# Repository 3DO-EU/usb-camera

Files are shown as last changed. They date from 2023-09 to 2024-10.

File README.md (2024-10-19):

# 3DO 4K USB CAMERA

**This repository is archived. Please visit the new project at [https://github.com/3DO-EU/Enclosure-Nozzle-Camera-V2](https://github.com/3DO-EU/Enclosure-Nozzle-Camera-V2)**

3DO Discord Server

The 3DO USB Camera is a compact USB camera based on the IMX485 sensor, designed for use with 3D printers.
This repository contains reference designs; additional resources may be found on printables.com or similar platforms.

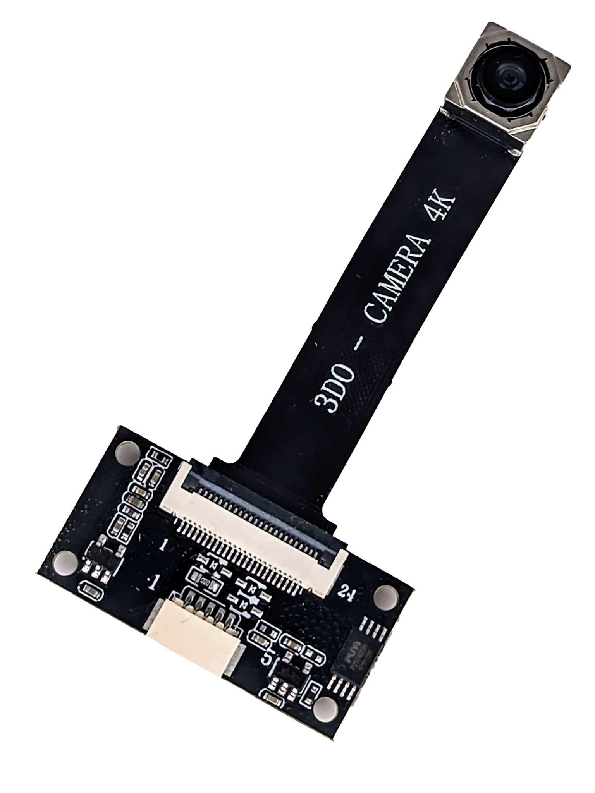
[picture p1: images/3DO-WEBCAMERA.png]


| | 4K (Sony IMX258) |
|---|---|
| Sensor Size | 1/3.06 |
| Mega-Pixel | 13MP |
| Frame Rate* | 30 FPS at 4K, 60 FPS at 1080P* |
| Lens type | Auto Focus |
| Focus length | 5 - ∞ cm |
| FoV | 120 Deg |
| FPC length | 5cm |
| Operating temperature** | -20°C TO 65°C |
| Storage temperature | -40°C TO 80°C |

_*These frame rates represent what the camera can achieve when directly connected, such as in OBS Studio or the Windows webcam app._

_When streaming through Crowsnest on a Raspberry Pi or a similar device, two factors limit your performance: GPU power and bandwidth._

_The new version of Crowsnest supports WebRTC/H.264 streaming, significantly reducing bandwidth requirements, making it less of a concern. However, when using the WebRTC streaming function, your GPU's encoding capabilities become the limiting factor (For Raspberry Pi 4, the GPU is limited to 1080p at 38 FPS and cannot encode 4K)._

_If you opt for the MJPEG stream in Crowsnest, no encoding is necessary, eliminating GPU limitations. However, this method requires considerably more bandwidth, so your FPS will be restricted by the available network bandwidth (using an Ethernet cable instead of Wi-Fi is recommended)._

## Folders
- printers (mounts for different printers)
- hardware (similar to [3DO Nozzle camera](https://github.com/3DO-EU/nozzle-camera/tree/main/hardware))

## Pinout
The PCB uses a 5P 1.0mm pitch connector.
| Pin No. | Function | Color |
|---|---|---|
| 1 | USB 5VDC | Red |
| 2 | Data - | White |
| 3 | Data + | Green |
| 4 | USB -VDC/GND | Black |
| 5 | GND/Shield | Black (heat shrink)  |

Wire number 5 is an optional shield/drain wire, though it will work without it; we recommend installing it.

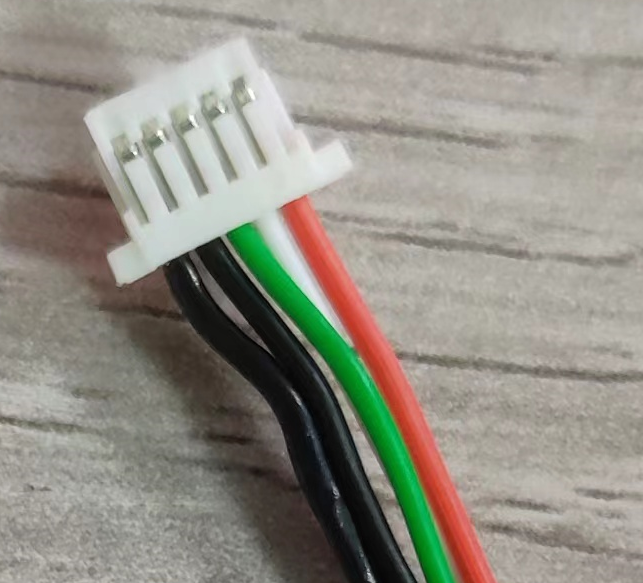
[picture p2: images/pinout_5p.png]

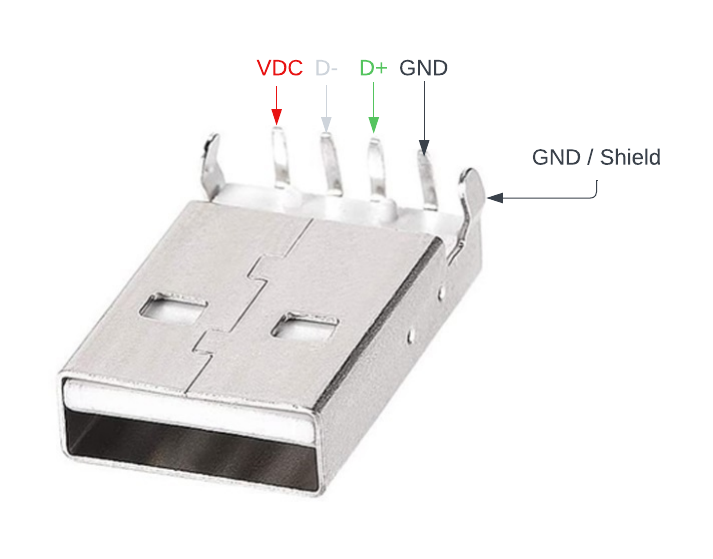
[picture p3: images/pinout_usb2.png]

</br> 

## Software
The camera functions as a standard UVC web camera and is, therefore, compatible with Linux, Windows, and Mac.
For streaming, we recommend using [mainsail](https://github.com/mainsail-crew/mainsail) + [crowsnest](https://github.com/mainsail-crew/crowsnest). 

## FAQ
- Does it work in an enclosed printer?

Yes, although our camera is rated at 60°C, we have been running it for 48 hours in a 70°C industrial heat chamber without any issues.

- Can I bend/fold the FPC to make it shorter?

Yes, the FPC is flexible and can be bent. If you want to fold it (180 degrees), we recommend doing this at most one time in the same spot; otherwise, you risk breaking the lanes inside the FPC.

Example of folding FPC

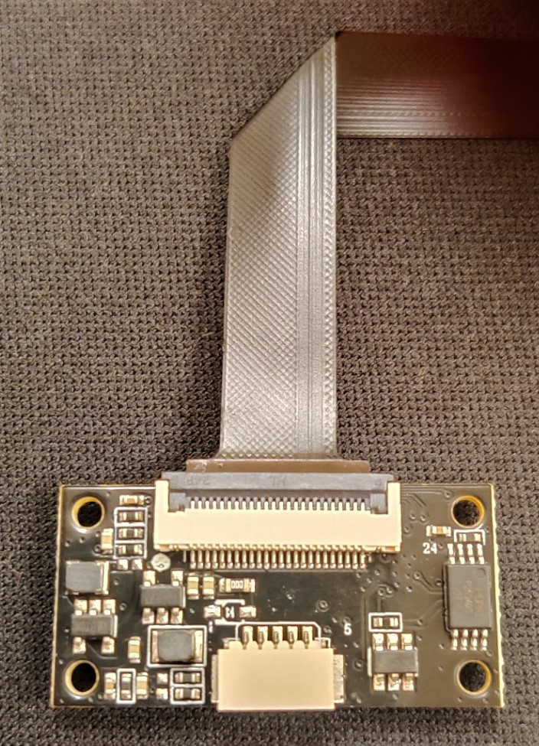
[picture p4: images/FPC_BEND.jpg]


## Where to buy
EU / UK



USA 





<p xmlns:cc="http://creativecommons.org/ns#" >This work is licensed under <a href="https://creativecommons.org/licenses/by-nc-sa/4.0/?ref=chooser-v1" target="_blank" rel="license noopener noreferrer" style="display:inline-block;">CC BY-NC-SA 4.0</a></p>

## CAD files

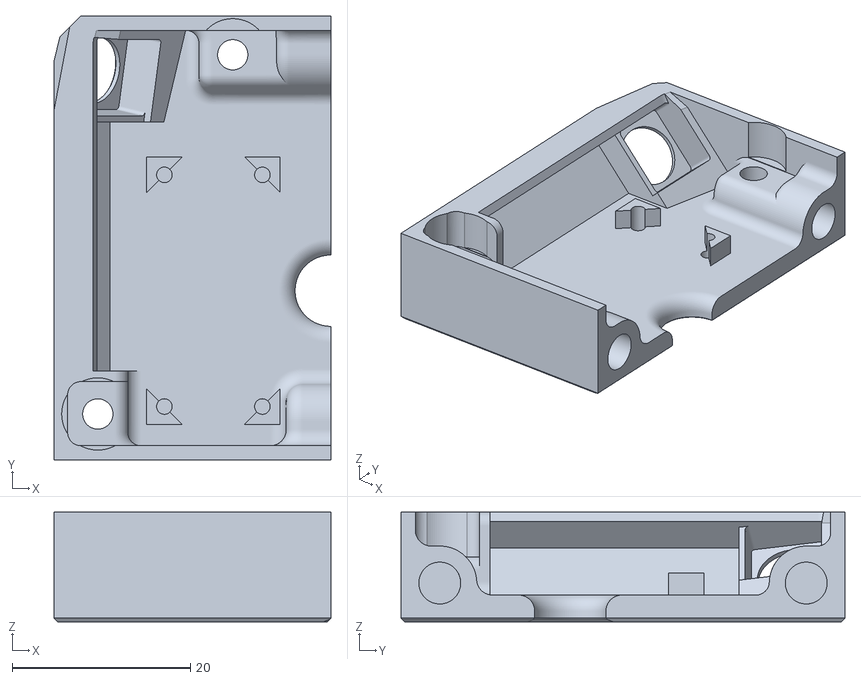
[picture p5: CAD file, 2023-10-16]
printers/voron_v2_4/STL/3DO_USB_Camera_v2.4_corner_mount_A3_v16-Main_body.stl
31.0 x 49.8 x 12.3

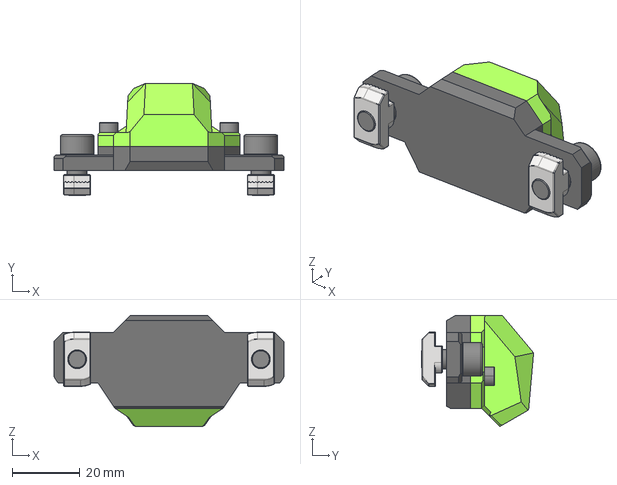
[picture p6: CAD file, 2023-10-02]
printers/ratrig_vcore/CAD/3DO_usb_cam_Ratrig.stp
68.0 x 33.2 x 32.9 mm

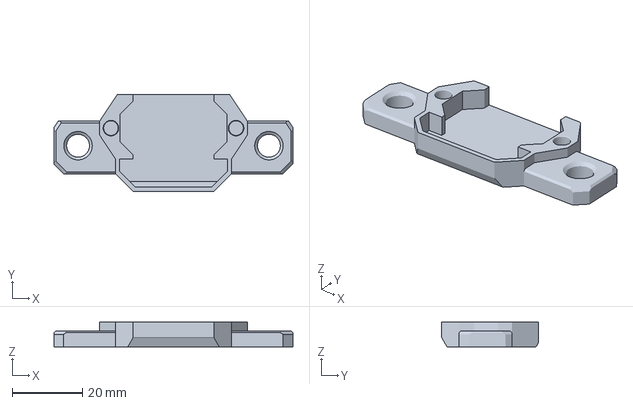
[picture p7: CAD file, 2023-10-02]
printers/ratrig_vcore/STL/3DO usb cam baseplate.3mf
68.0 x 27.5 x 7.00 mm

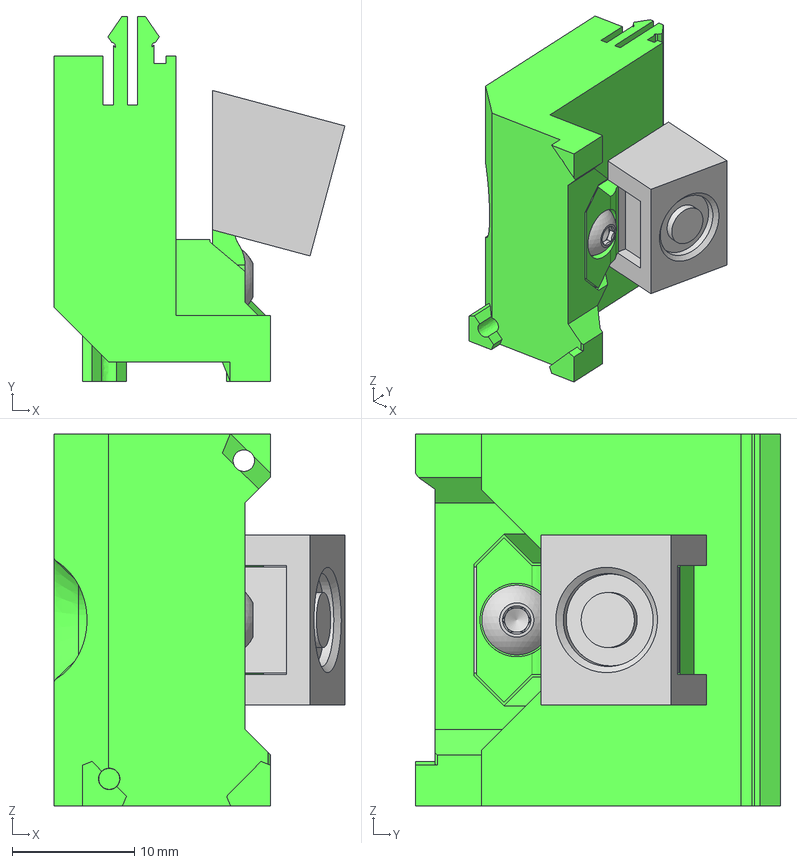
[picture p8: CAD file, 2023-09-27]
printers/voron_v0/CAD/voron_0_nozzle_cam_frame_v2.step
23.8 x 29.9 x 30.4 mm
Brackets_1515_x2 v1 (1)
M3 Threaded Insert
camera
camera holder
pcb holder
camera stick
M3x8 BHCS
PCB_mount_SB v1

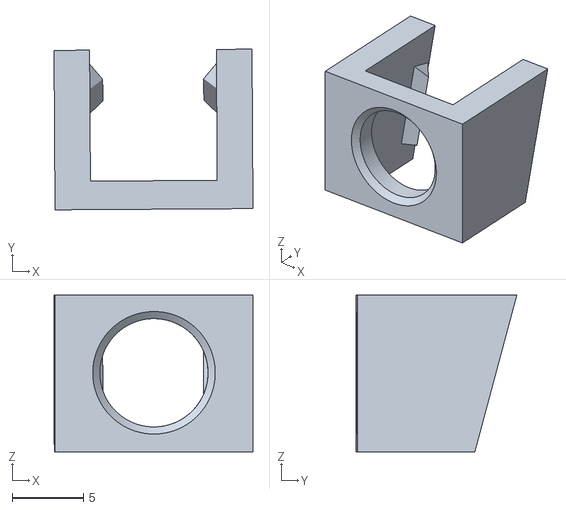
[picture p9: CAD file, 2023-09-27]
printers/voron_v0/STL/camera_holder.stl
14.0 x 11.3 x 11.0

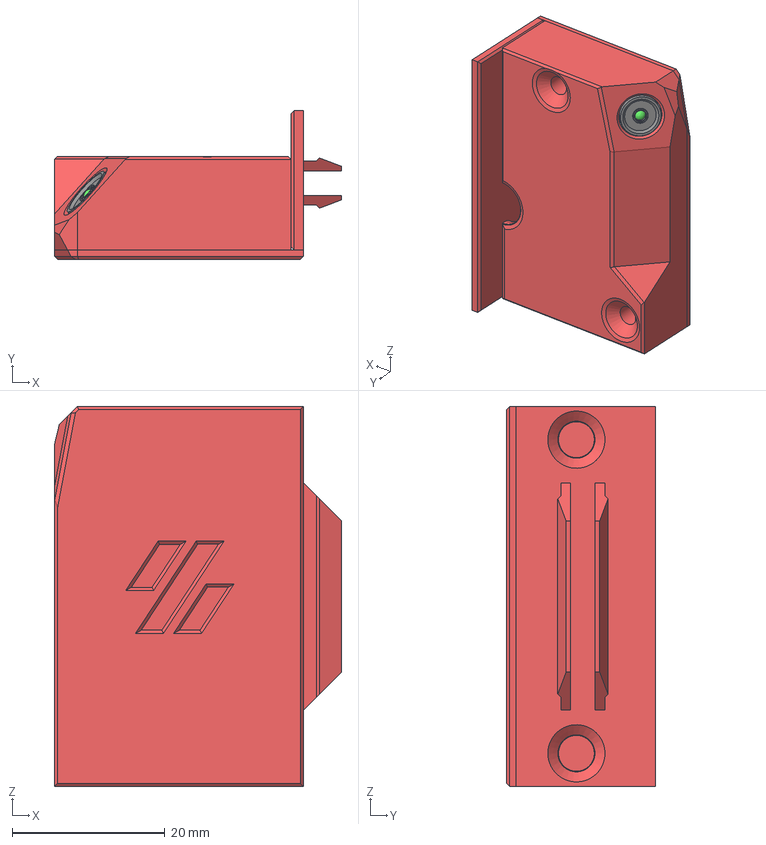
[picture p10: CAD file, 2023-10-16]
printers/voron_v2_4/CAD/3DO_Webcam_Corner_mount_A3_v16.step
37.6 x 19.5 x 49.8 mm
Camera
FPC
Camera house
Extrusion mount

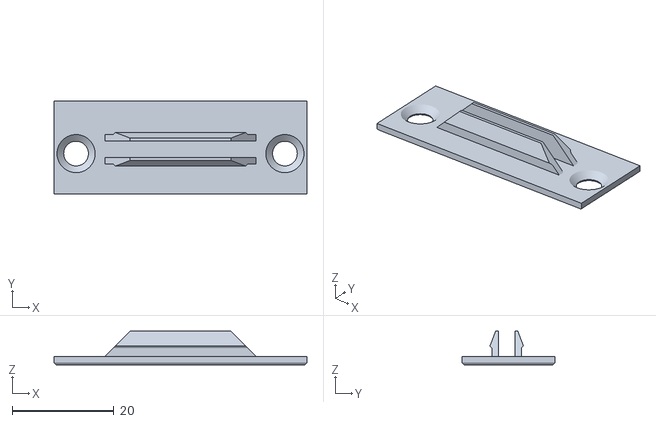
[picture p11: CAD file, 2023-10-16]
printers/voron_v2_4/STL/3DO_USB_Camera_v2.4_corner_mount_A3_v16-Extrusion_mount.stl
49.8 x 18.3 x 6.60

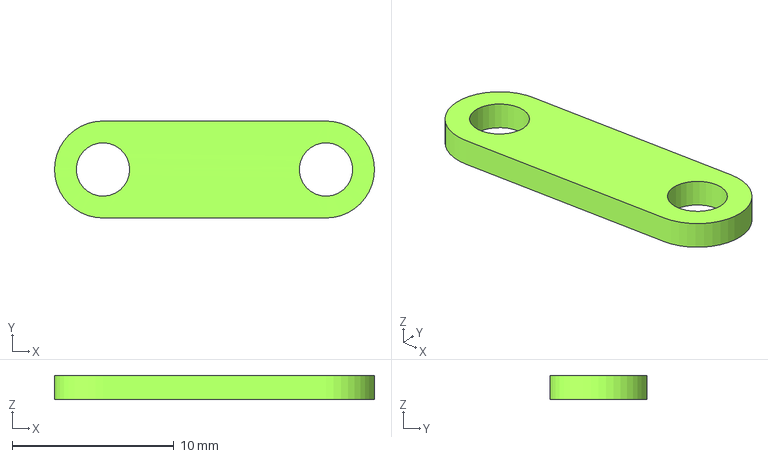
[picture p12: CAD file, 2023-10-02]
printers/ratrig_vcore/STL/3DO usb cam Clamp.3mf
19.8 x 6.00 x 1.50 mm

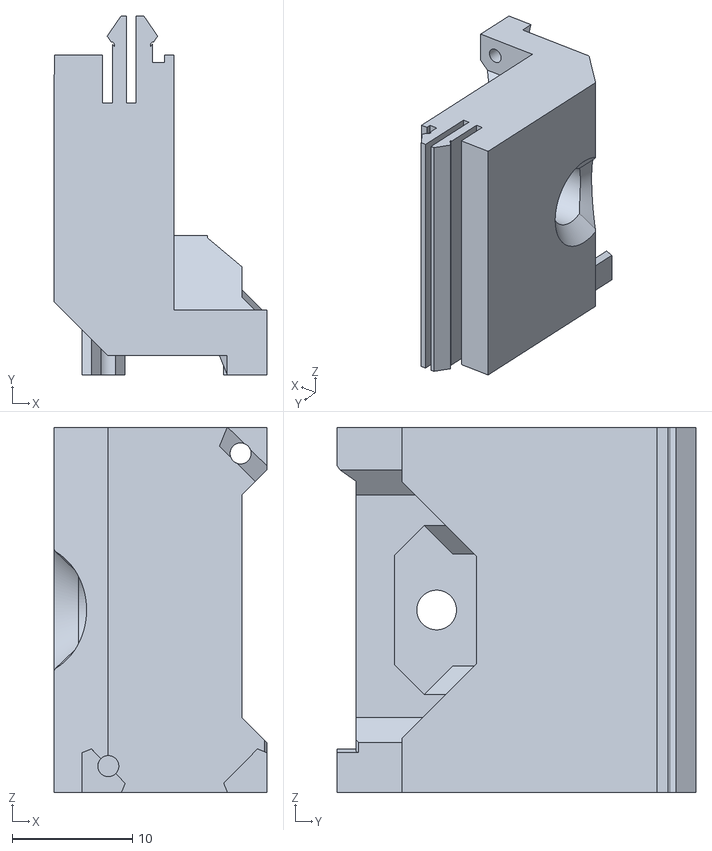
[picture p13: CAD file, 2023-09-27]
printers/voron_v0/STL/pcb_holder.stl
17.7 x 29.9 x 30.4

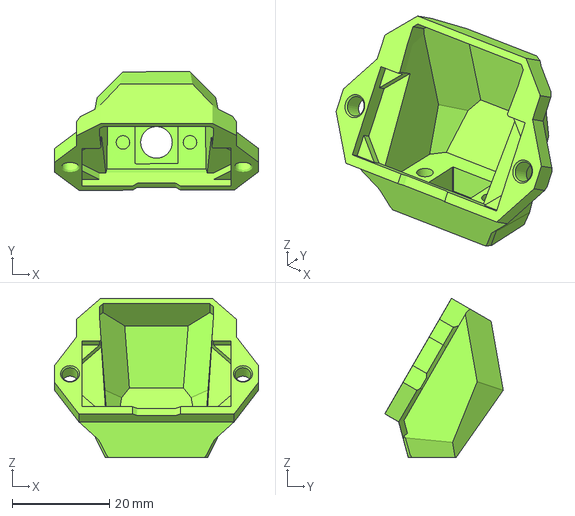
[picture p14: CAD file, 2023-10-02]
printers/ratrig_vcore/STL/3DO usb cam House.3mf
42.0 x 24.4 x 32.8 mm

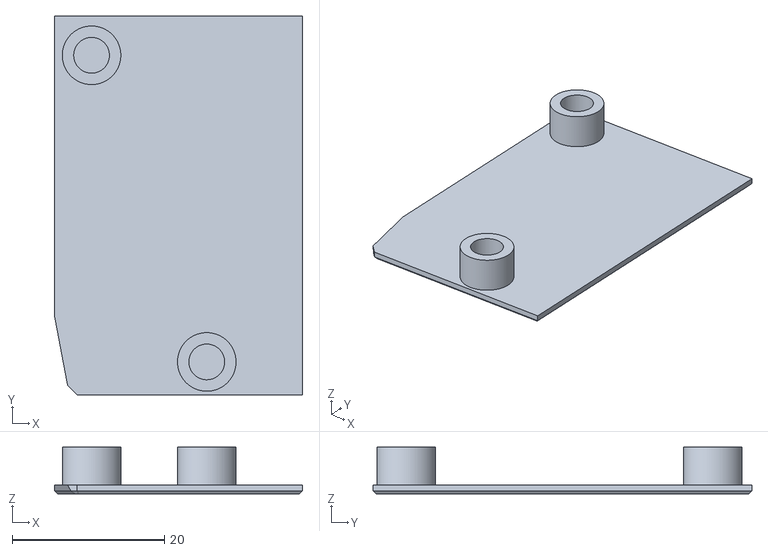
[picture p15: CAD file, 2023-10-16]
printers/voron_v2_4/STL/3DO_USB_Camera_v2.4_corner_mount_A3_v16-Cover_Voron_logo.stl
32.6 x 49.8 x 6.15

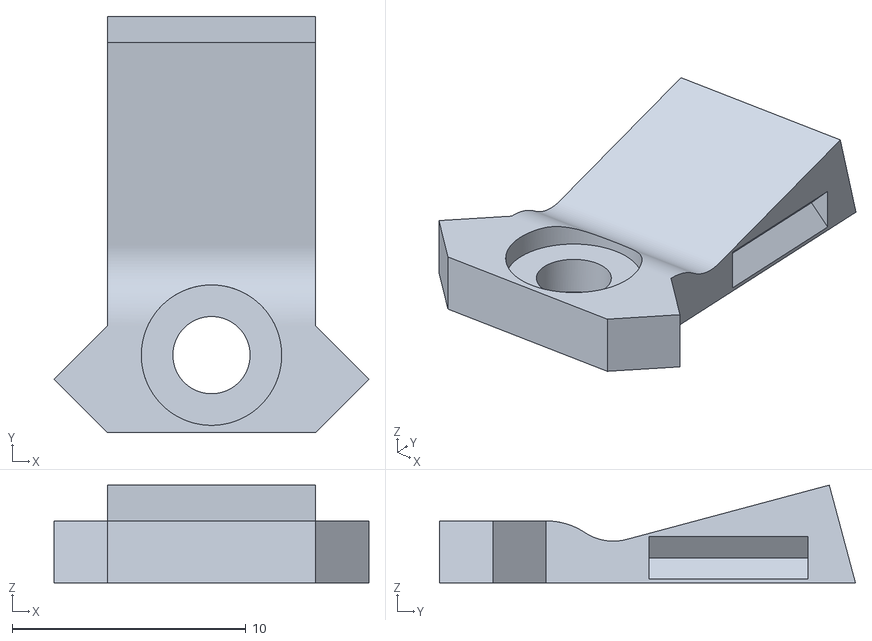
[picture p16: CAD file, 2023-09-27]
printers/voron_v0/STL/camera_stick.stl
13.5 x 17.8 x 4.18

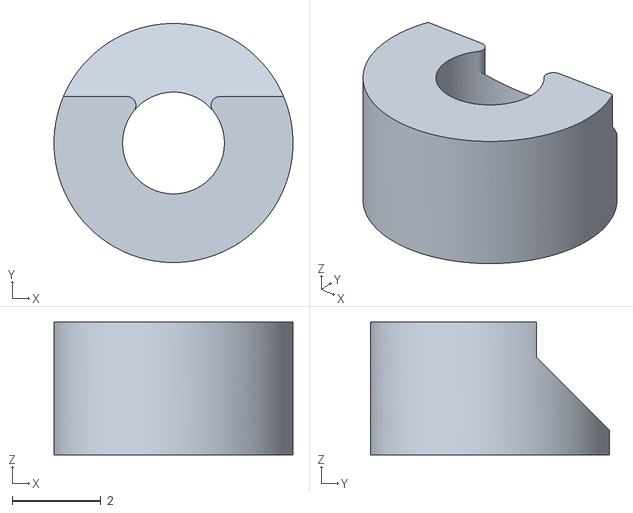
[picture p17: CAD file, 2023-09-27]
printers/voron_v0/STL/pcb_m2_washer_x2.stl
5.40 x 5.40 x 3.00

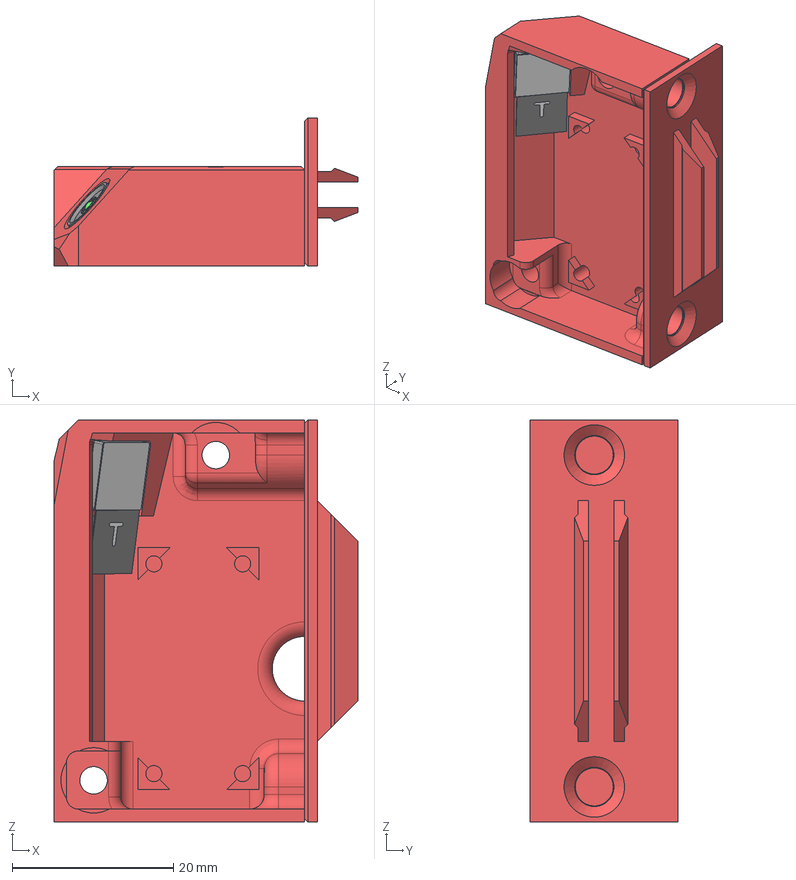
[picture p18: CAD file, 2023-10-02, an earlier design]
printers/voron_v2_4/CAD/3DO_Webcam_Corner_mount_A3_v10.step
37.6 x 18.3 x 49.8 mm
Camera
FPC
Camera house
Extrusion mount

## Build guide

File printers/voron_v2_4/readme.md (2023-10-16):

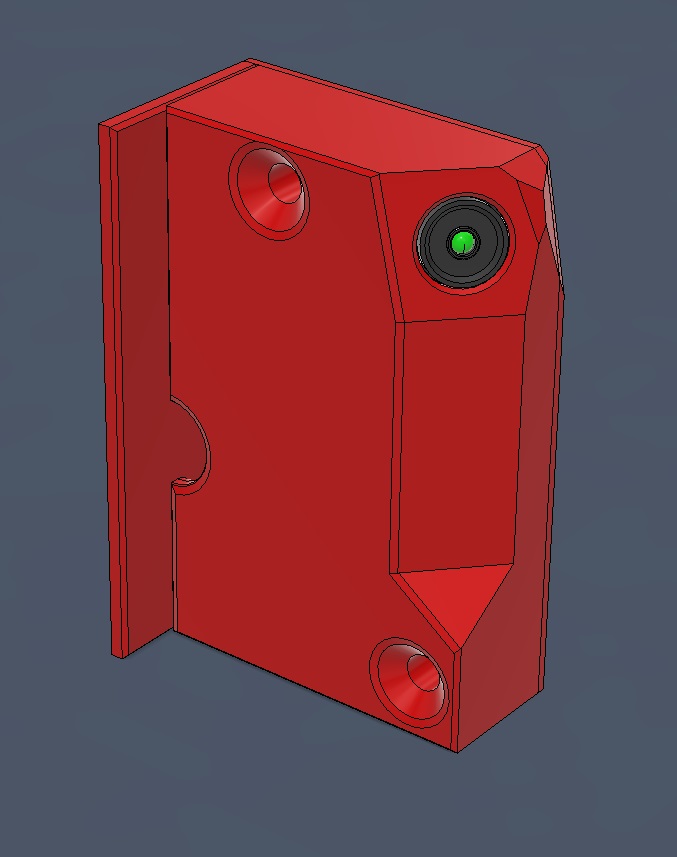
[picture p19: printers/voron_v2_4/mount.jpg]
<br/>
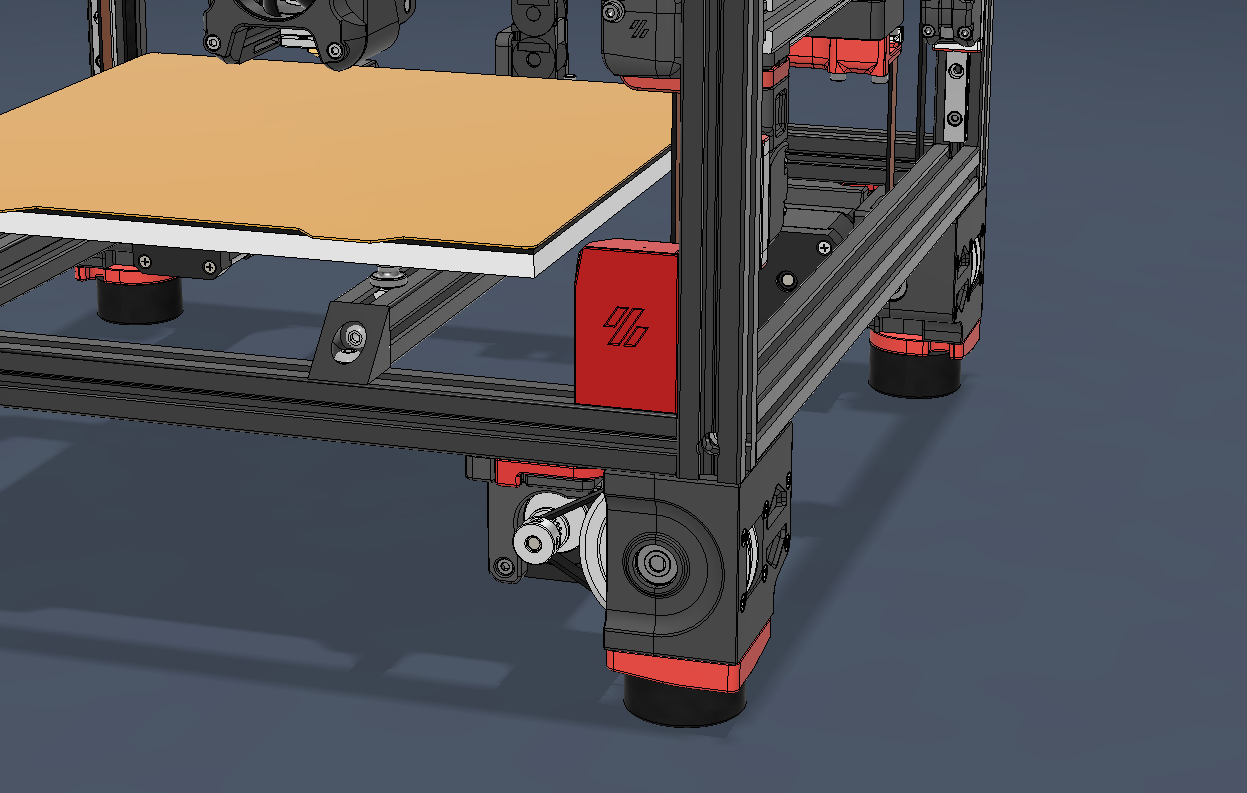
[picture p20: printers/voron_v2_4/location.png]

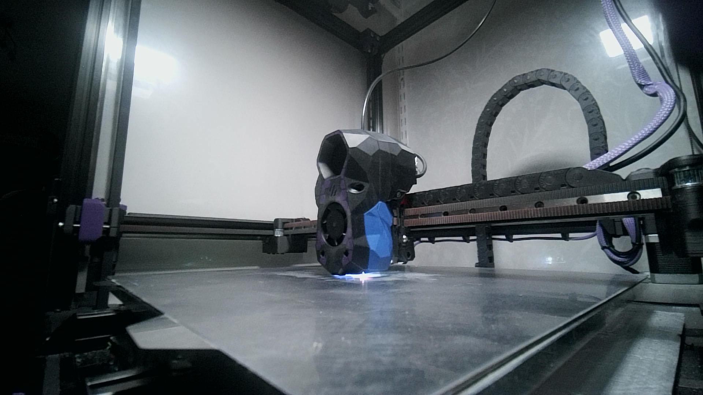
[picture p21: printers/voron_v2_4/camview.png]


### BOM
4x M3x4x5 heatsets (Voron standard)

2x M3x6 FHCS

2x M3x12 FHCS

2-4x M2x10 Self tapping screws

Use the Voron [ADXL washers](https://github.com/VoronDesign/Voron-Stealthburner/tree/main/STLs/Stealthburner/ADXL345_Mounts "ADXL washers") to space out the screw heads of the M2x10 self tappers from the PCB. Otherwise there is a risk to damage the PCB.

### Credits
- Zruncho for his [ZeroPanels](https://github.com/zruncho3d/ZeroPanels "ZeroPanels") design that inspired the mounting mechanism. 
- Voron for their [ADXL washers](https://github.com/VoronDesign/Voron-Stealthburner/tree/main/STLs/Stealthburner/ADXL345_Mounts "ADXL washers")

Design by Panzarkatten

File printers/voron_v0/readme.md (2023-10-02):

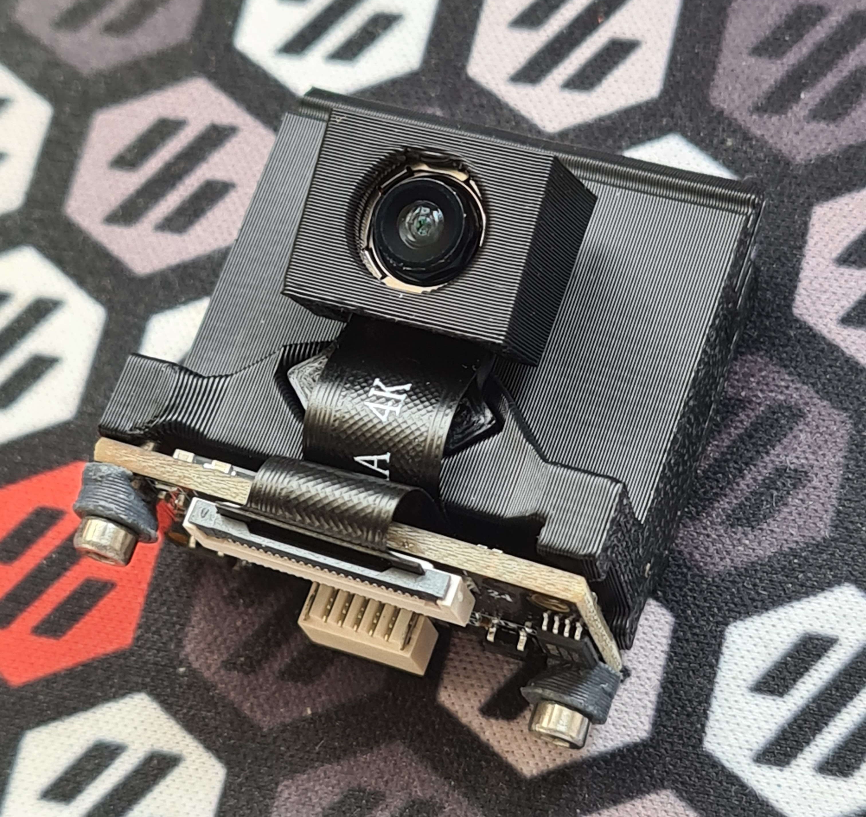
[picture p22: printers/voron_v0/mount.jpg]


### BOM
1x M3x6-14 BHCS

1x M3 heatinsert

2x M2x10 self tapping screws

### Credits
- Zruncho for hes [ZeroPanels](https://github.com/zruncho3d/ZeroPanels "ZeroPanels") design
- Voron for their [ADXL washers](https://github.com/VoronDesign/Voron-Stealthburner/tree/main/STLs/Stealthburner/ADXL345_Mounts "ADXL washers")

Design by Olof Ogland

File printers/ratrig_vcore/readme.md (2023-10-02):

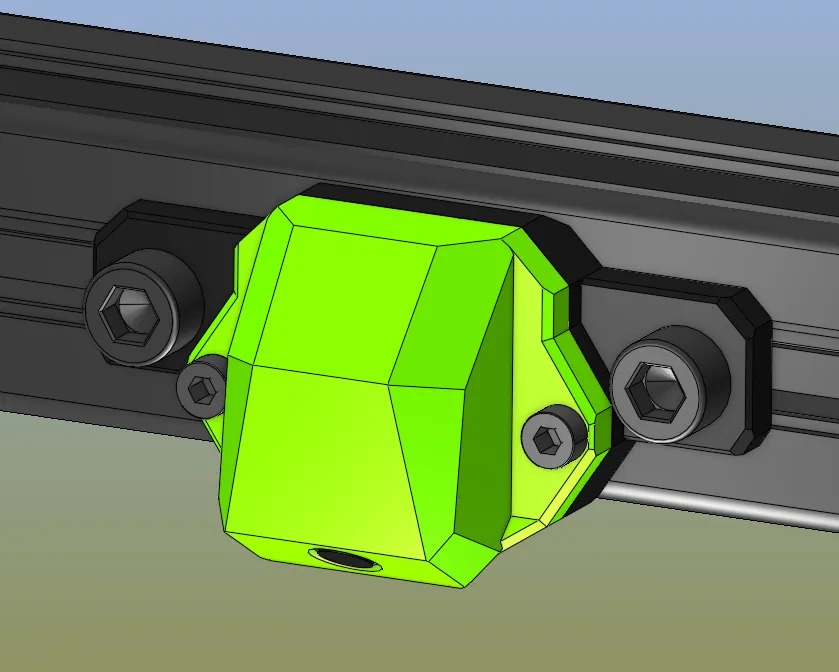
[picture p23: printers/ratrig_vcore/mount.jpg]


### BOM
2 pcs M3x6 (to clamp the camera to the housing)

2 pcs M3x8-10 + 2 pcs M3 heat-inserts (to mount the housing to baseplate)

2 pcs M6x12 + t-nuts (to mount to the 3030 profile)

Design by Dennis Jespersen

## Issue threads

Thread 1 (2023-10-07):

PCB Keep out around screw holes

SNR-Tech-Bytes, 2023-10-07:
So far loving my enclosure cam its great! I did notice while installing the screws to hold the board in place that there are resistors and IC's dangerously close to the screw holes. One of my screws was shorting the pins on the puya flash chip (fortunately I noticed before I powered it on). Anyway something to address in a future revision!

thbl, 2023-10-16:
fixed with #3

Closed 2023-10-16.

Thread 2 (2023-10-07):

No IR Filter Version?

SNR-Tech-Bytes, 2023-10-07:
For a future product, perhaps using a camera sensor without an IR filter! Especially for overnight 3d prints I like having all the lights off but using IR floodlights the camera (and ultimately obico) can still keep an eye on the print!

For anyone who stumbles across this post in the future, this camera does have an IR filter in it!

thbl, 2023-10-16:
will consider it

Closed 2023-10-16.

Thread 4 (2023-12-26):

Created a usb-camera mount for the VzBot330

Julzu93, 2023-12-26:
Hi,

I created a version of the usb-camera mount I would like to add in the "usb-camera/printers" section.
Uploaded the files to my github if you would like to check it out 👍

https://github.com/Julzu93/VzBoT-Vz330/tree/main/VzBoT-Vz330

Closed 2024-05-27.
